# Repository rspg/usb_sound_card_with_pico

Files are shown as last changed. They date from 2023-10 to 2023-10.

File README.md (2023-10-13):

:point_right: [Japanese](./README_jp.md)

# USB Sound Card with Raspberry Pi Pico

## Introduction

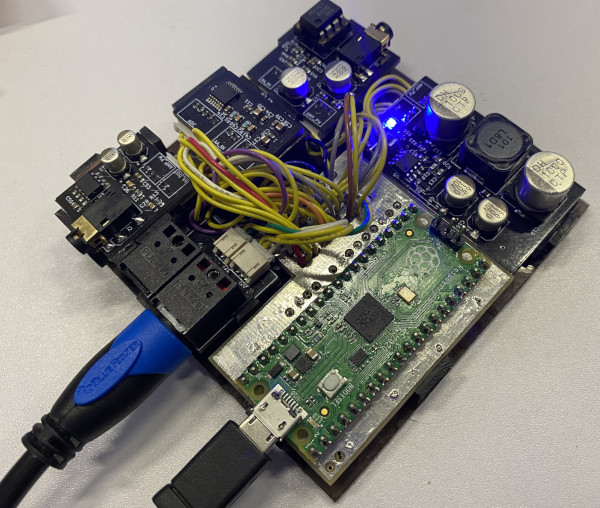
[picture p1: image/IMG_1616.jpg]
Complete image


This is a project for a USB sound card constructed with a Raspberry Pi Pico microcontroller board.  
Hardware schematics and firmware sourcecode are included.

## Features

- USB Audio Class 2.0 (Connected by USB 2.0 Full speed)
- 2ch Line in
- 2ch Line out
- 2ch SPDIF in
- 2ch SPDIF out
- 2ch Headphone out
- Maximum resolution is 24bit
- Maximum frequency is 96KHz

In/out USB data streams cannot activate simultaneously at 24-bit/96KHz due to a lack of transfer bandwidth.
"Line in" and "SPDIF in" are mixed into one buffer to save USB bandwidth. Each volume can be controlled via a generic USB driver. (Currently, it only supports Windows WinUSB.)

## Hardware

I used KiCad6 to design the schematics.  
If you want to view the schematics, Please download [KiCad 6 or later](https://www.kicad.org/).

The hardware design is simple and lacks ingenuity because I am not an electronics expert.
But I designed the schematics with the concept of separating modules by function to facilitate testing and adding other functions.  
Electronic components which are used are general and easily obtainable.   
The DAC uses PCM5102a and may be easily replaced with any of the PCM510x series. You can choose depending on their availability (although I have never tried this).

## Firmware 

The firmware is wrote by C and C++. 
SPDIF control does not use dedicated hardware and is implemented by the software using one of Pico's features called PIO. It allows running I/O independently of the main processor.
Similar to the schematics, the software is also organized by function. Each hardware function is represented as a class in the software.

To build the firmware, you should first install Pico's SDK and CMake.
For detailed instructions, please refer to the following resources.
- [Raspberry Pi Documentation The C/C++ SDK](https://www.raspberrypi.com/documentation/microcontrollers/c_sdk.html)  
- [CMake](https://cmake.org/)

Let's prepare a directory for Cmake setup.
> mkdir build  
> cd build  

For standard setup
> cmake ..  

With tracing log
> cmake .. -DLOG=1   

'LOG' is passed to tinyusb's debug level. That description is [here](https://docs.tinyusb.org/en/latest/reference/getting_started.html#log).

With profiling
> cmake .. -DPROFILE=1

To usb device control use TinyUSB. It is included in PicoSDK.
TinyUSB for Pico has a problem what memory deallocation of endpoint. Therefore, I prepared [a patch](patch/tinyusb-rp2040-allow-memory-preallocation.patch) for avoiding it. 
If you encounter to crashing the device in TinyUSB memory allocation,
It may resolve by applying [the patch](patch/tinyusb-rp2040-allow-memory-preallocation.patch) to TinyUSB.

## Debugging

The device outputs tracing log to serial port (CDC) owned myself. You can see the contents via serial monitor.   
And following commands are usable via serial monitor input.

> stats_on

Turn on the output of internal statistics every 0.5 seconds when the LOG is greater than 0.
 
> stats_off

Turn on output of internal stats.

> perf

Output measured performance statistics when profiling is enabled.

## Device unique request (Windows Only)
Unique requests to control internal behaviors from the host device have been implemented in the firmware.
If the host OS is Windows, the device requests the installation of the WinUSB driver to the OS through the Microsoft OS Descriptor description. This enables user-mode applications on the host to send requests to the device.

[control_uwp](control_uwp) is an application to controls the device volumes by using WinUSB via Windows Runtime.
To building requires [Visual Studio 2022 with C# UWP application development](https://visualstudio.microsoft.com/).

## References
- [Raspberry Pi Pico Datasheet](https://datasheets.raspberrypi.com/pico/pico-datasheet.pdf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.)  
- [RP2040 Datasheet](https://datasheets.raspberrypi.com/rp2040/rp2040-datasheet.pdf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.)    
- [SPECIFICATION OF THE DIGITAL AUDIO INTERFACE (The AES/EBU interface)](https://tech.ebu.ch/docs/tech/tech3250.pdf)
- [Texas Instruments PCM510xA 2.1 VRMS, 112/106/100 dB Audio Stereo DAC with PLL and 32-bit, 384 kHz PCM Interface](https://www.ti.com/lit/ds/symlink/pcm5102a.pdf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)
- [Texas Instruments PCM1808 Single-Ended, Analog-Input 24-Bit, 96-kHz Stereo ADC](https://www.ti.com/jp/lit/ds/symlink/pcm1808.pdf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)

## Disclaimer

I am not responsible and cannot guarantee any damage or injury that may occur if you decide to undertake this project.
Please keep in mind that this is a DIY project.

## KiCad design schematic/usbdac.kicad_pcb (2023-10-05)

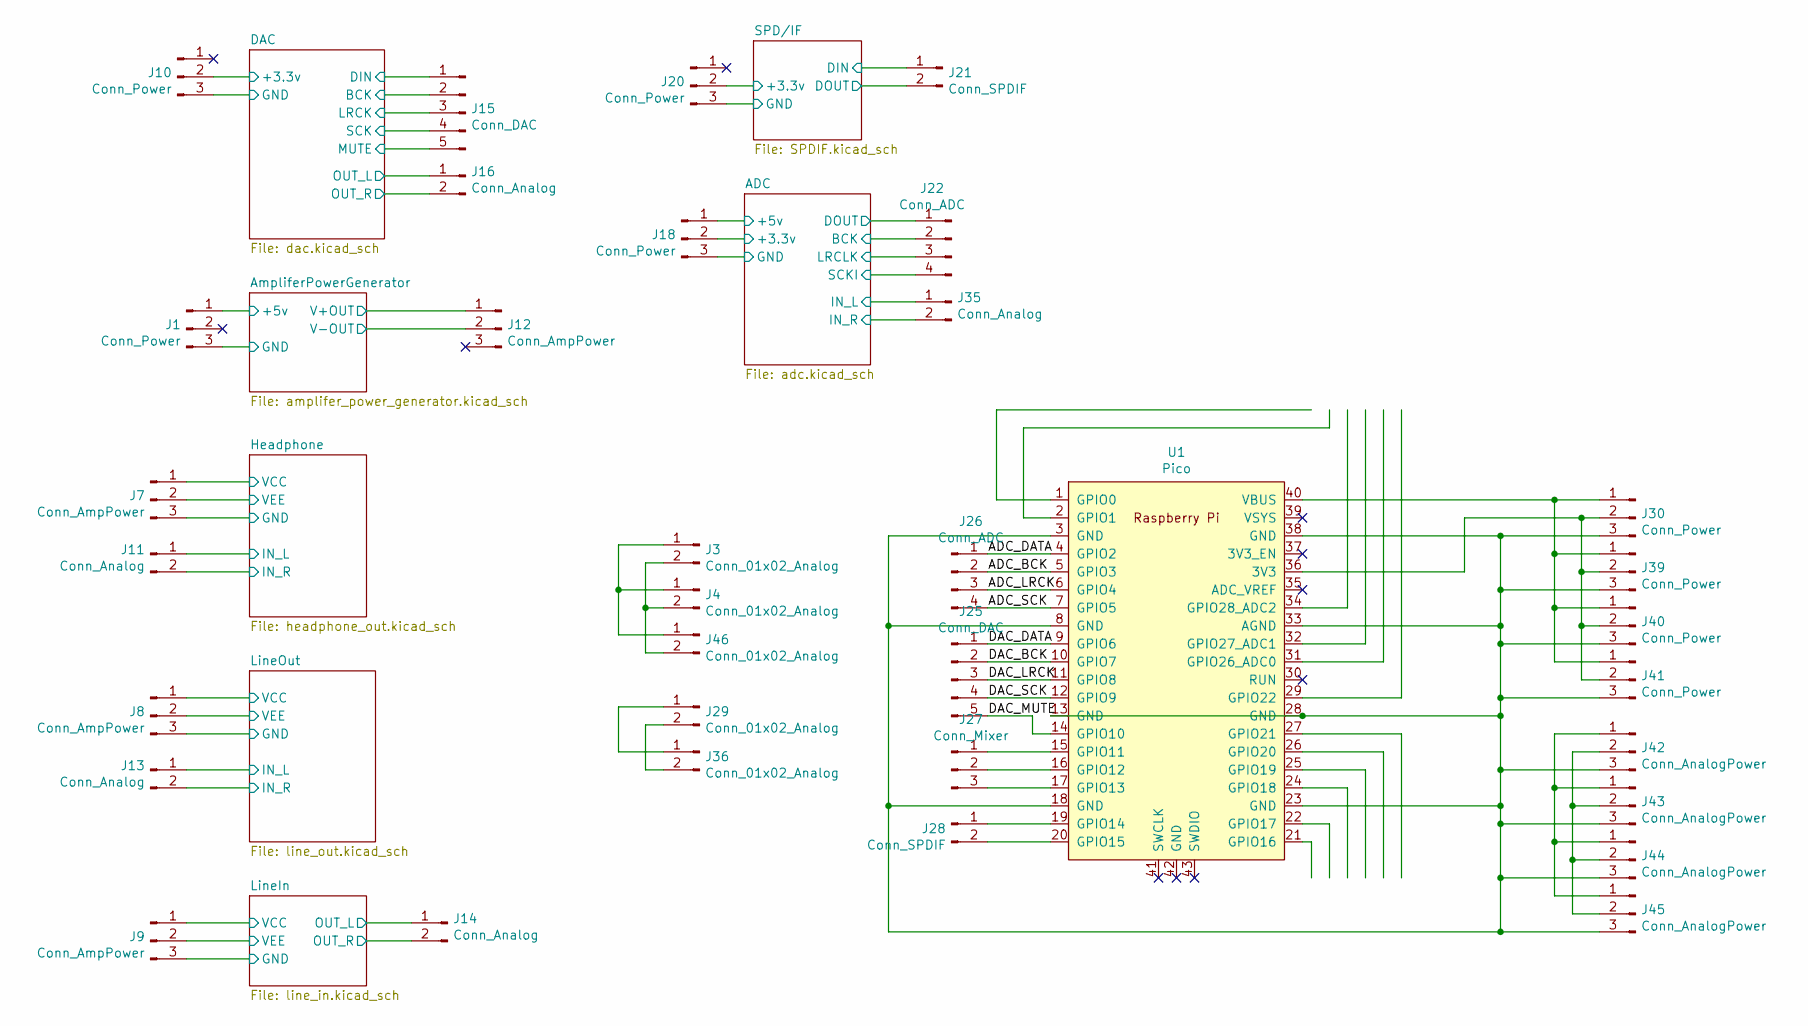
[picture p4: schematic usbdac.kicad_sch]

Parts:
J1, J10, J18, J20: Conn_Power; JST_ZH_S2B_ZR_1x03_P1.50mm_Horizontal_2layer
J3, J4, J29, J36, J46: Conn_01x02_Analog; PinHeader_1x02_P2.00mm_Vertical
J7, J8, J9, J12: Conn_AmpPower; JST_ZH_S2B_ZR_1x03_P1.50mm_Horizontal_2layer
J11, J13, J14, J16, J35: Conn_Analog; JST_ZH_S2B_ZR_1x02_P1.50mm_Horizontal_2layer
J15: Conn_DAC; JST_ZH_S2B_ZR_1x05_P1.50mm_Horizontal_2layer
J21: Conn_SPDIF; JST_ZH_S2B_ZR_1x02_P1.50mm_Horizontal_2layer
J22: Conn_ADC; JST_ZH_S2B_ZR_1x05_P1.50mm_Horizontal_2layer
J25: Conn_DAC; PinHeader_1x05_P2.00mm_Vertical
J26: Conn_ADC; PinHeader_1x04_P2.00mm_Vertical
J27: Conn_Mixer; PinHeader_1x03_P2.00mm_Vertical
J28: Conn_SPDIF; PinHeader_1x02_P2.00mm_Vertical
J30, J39, J40, J41: Conn_Power; PinHeader_1x03_P2.00mm_Vertical
J42, J43, J44, J45: Conn_AnalogPower; PinHeader_1x03_P2.00mm_Vertical
U1: Pico; RPi_Pico_WithPinHeader

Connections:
/ADC/+3.3v: J18.2; also elsewhere on the board
/ADC/+5v: J18.1; also elsewhere on the board
/ADC/BCK: J22.2; also elsewhere on the board
/ADC/DOUT: J22.1; also elsewhere on the board
/ADC/GND: J18.3; also elsewhere on the board
/ADC/IN_L: J35.1; also elsewhere on the board
/ADC/IN_R: J35.2; also elsewhere on the board
/ADC/LRCLK: J22.3; also elsewhere on the board
/ADC/SCKI: J22.4; also elsewhere on the board
/ADC_BCK: J26.2, U1.5 (GPIO3)
/ADC_DATA: J26.1, U1.4 (GPIO2)
/ADC_LRCK: J26.3, U1.6 (GPIO4)
/ADC_SCK: J26.4, U1.7 (GPIO5)
/AmpliferPowerGenerator/+5v: J1.1, J12.1; also elsewhere on the board
/AmpliferPowerGenerator/GND: J1.3; also elsewhere on the board
/AmpliferPowerGenerator/V-OUT: J12.2; also elsewhere on the board
/DAC/+3.3v: J10.2; also elsewhere on the board
/DAC/BCK: J15.2; also elsewhere on the board
/DAC/DIN: J15.1; also elsewhere on the board
/DAC/GND: J10.3; also elsewhere on the board
/DAC/LRCK: J15.3; also elsewhere on the board
/DAC/MUTE: J15.5; also elsewhere on the board
/DAC/OUT_L: J16.1; also elsewhere on the board
/DAC/OUT_R: J16.2; also elsewhere on the board
/DAC/SCK: J15.4; also elsewhere on the board
/DAC_BCK: J25.2, U1.10 (GPIO7)
/DAC_DATA: J25.1, U1.9 (GPIO6)
/DAC_LRCK: J25.3, U1.11 (GPIO8)
/DAC_MUTE: J25.5, U1.14 (GPIO10)
/DAC_SCK: J25.4, U1.12 (GPIO9)
/Headphone/GND: J7.3; also elsewhere on the board
/Headphone/IN_L: J11.1; also elsewhere on the board
/Headphone/IN_R: J11.2; also elsewhere on the board
/Headphone/VCC: J7.1; also elsewhere on the board
/Headphone/VEE: J7.2; also elsewhere on the board
/LineIn/GND: J9.3; also elsewhere on the board
/LineIn/OUT_L: J14.1; also elsewhere on the board
/LineIn/OUT_R: J14.2; also elsewhere on the board
/LineIn/VCC: J9.1; also elsewhere on the board
/LineIn/VEE: J9.2; also elsewhere on the board
/LineOut/GND: J8.3; also elsewhere on the board
/LineOut/IN_L: J13.1; also elsewhere on the board
/LineOut/IN_R: J13.2; also elsewhere on the board
/LineOut/VCC: J8.1; also elsewhere on the board
/LineOut/VEE: J8.2; also elsewhere on the board
/SPD/IF/+3.3v: J20.2; also elsewhere on the board
/SPD/IF/DIN: J21.1; also elsewhere on the board
/SPD/IF/DOUT: J21.2; also elsewhere on the board
/SPD/IF/GND: J20.3; also elsewhere on the board
unnamed: J3.1, J4.1, J46.1
unnamed: J3.2, J4.2, J46.2
unnamed: J27.1, U1.15 (GPIO11)
unnamed: J27.2, U1.16 (GPIO12)
unnamed: J27.3, U1.17 (GPIO13)
unnamed: J28.1, U1.19 (GPIO14)
unnamed: J28.2, U1.20 (GPIO15)
unnamed: J29.1, J36.1
unnamed: J29.2, J36.2
unnamed: J30.1, J39.1, J40.1, J41.1, U1.40 (VBUS)
unnamed: J30.2, J39.2, J40.2, J41.2, U1.36 (3V3)
unnamed: J30.3, J39.3, J40.3, J41.3, J42.3, J43.3, J44.3, J45.3, U1.3 (GND), U1.8 (GND), U1.13 (GND), U1.18 (GND), U1.23 (GND), U1.28 (GND), U1.33 (AGND), U1.38 (GND)
unnamed: J42.1, J43.1, J44.1, J45.1
unnamed: J42.2, J43.2, J44.2, J45.2

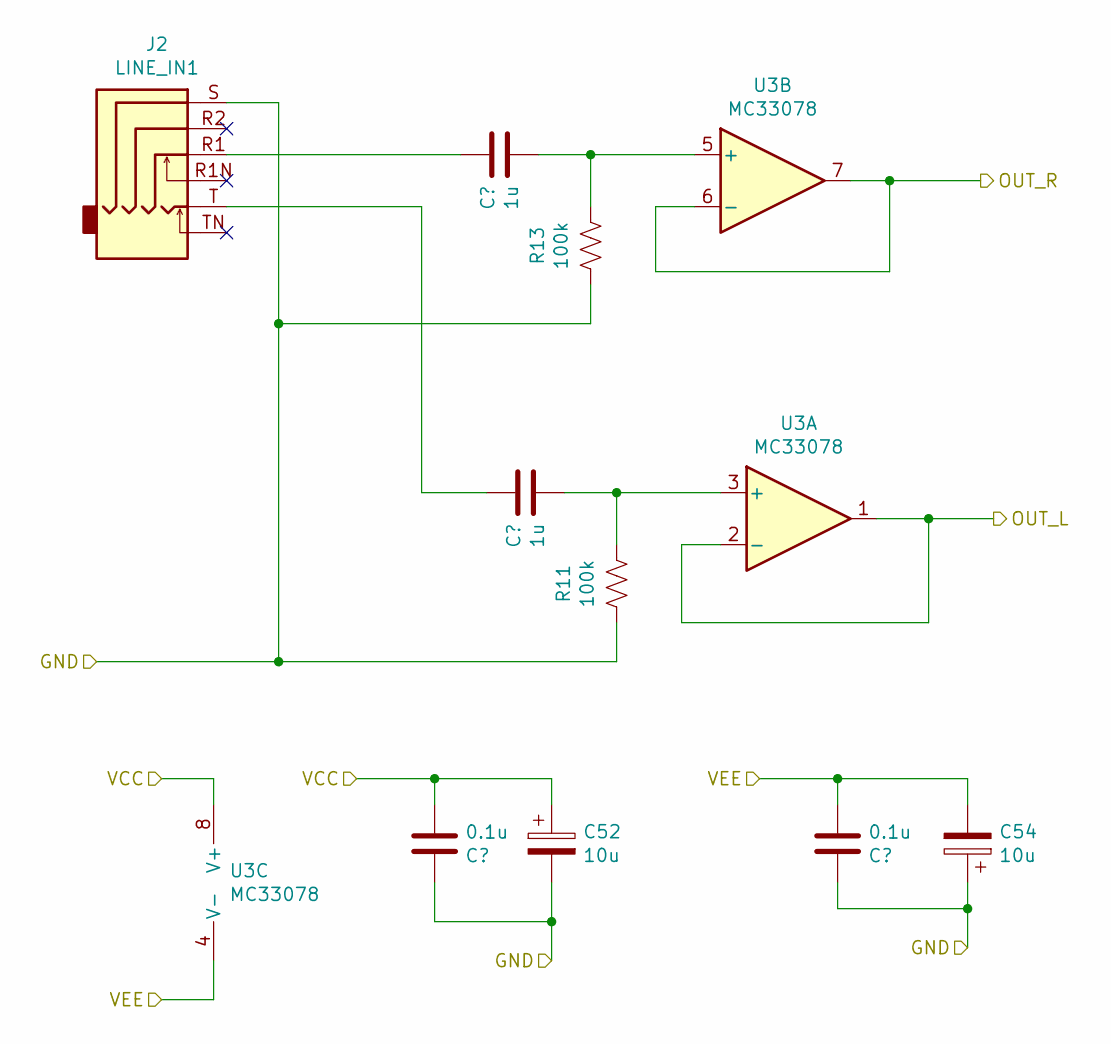
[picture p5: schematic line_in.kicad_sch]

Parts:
C26, C28: 1u; C_0603_1608Metric
C51, C53: 0.1u; C_0603_1608Metric
C52, C54: 10u; CP_Elec_4x3.9
J2: LINE_IN1; Jack_3.5mm_PJ31060-I_Horizontal
R11, R13: 100k; R_0603_1608Metric
U3: MC33078; SO-8_3.9x4.9mm_P1.27mm

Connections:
/LineIn/GND: C51.2, C52.2, C53.2, C54.1, J2.S, R11.1, R13.1; also elsewhere on the board
/LineIn/OUT_L: U3.1, U3.2 (-); also elsewhere on the board
/LineIn/OUT_R: U3.6 (-), U3.7; also elsewhere on the board
/LineIn/VCC: C51.1, C52.1, U3.8 (V+); also elsewhere on the board
/LineIn/VEE: C53.1, C54.2, U3.4 (V-); also elsewhere on the board
unnamed: C26.2, J2.T
unnamed: C28.2, J2.R1
unnamed: C26.1, R11.2, U3.3 (+)
unnamed: C28.1, R13.2, U3.5 (+)

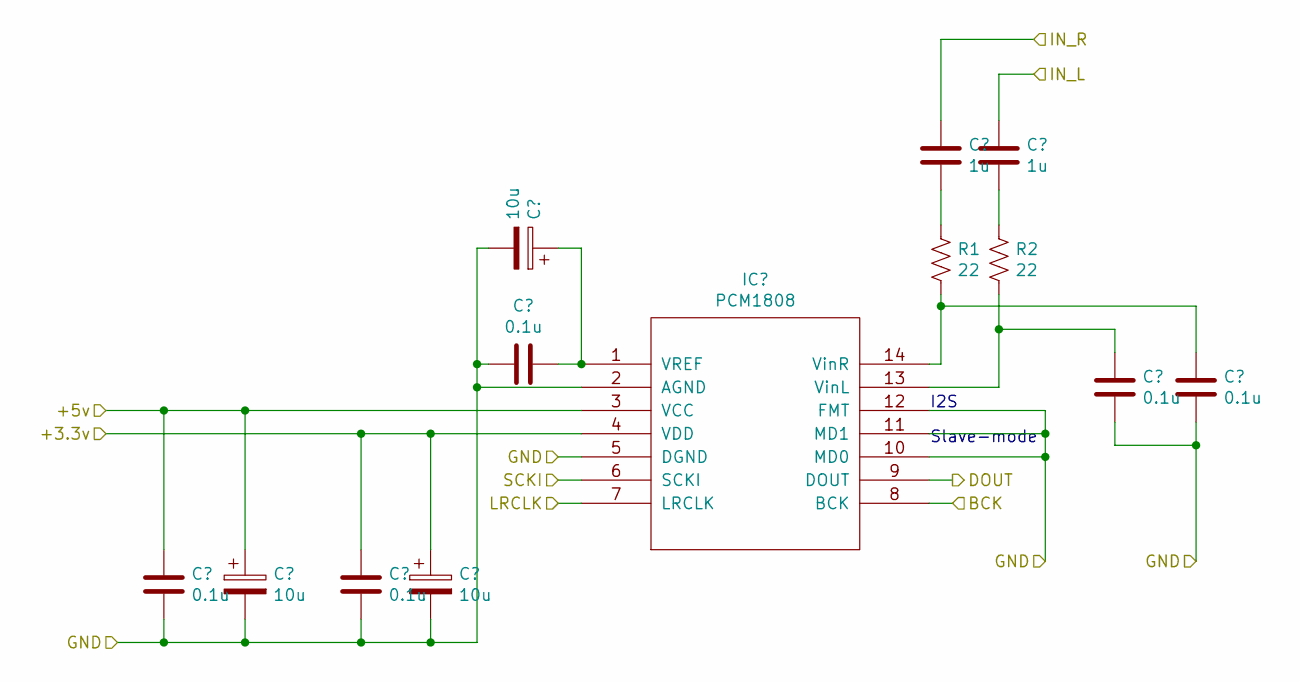
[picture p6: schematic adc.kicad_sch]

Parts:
C11, C14, C34, C36, C39: 0.1u; C_0603_1608Metric
C35, C37, C38: 10u; C_0603_1608Metric
C40, C41: 1u; C_0603_1608Metric
IC1: PCM1808; TI_R-PDSO-G14
R1, R2: 22; R_0603_1608Metric

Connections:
/ADC/+3.3v: C36.2, C37.1, IC1.4 (VDD); also elsewhere on the board
/ADC/+5v: C34.2, C35.1, IC1.3 (VCC); also elsewhere on the board
/ADC/BCK: IC1.8 (BCK); also elsewhere on the board
/ADC/DOUT: IC1.9 (DOUT); also elsewhere on the board
/ADC/GND: C11.1, C14.1, C34.1, C35.2, C36.1, C37.2, C38.2, C39.1, IC1.2 (AGND), IC1.5 (DGND), IC1.10 (MD0), IC1.11 (MD1), IC1.12 (FMT); also elsewhere on the board
/ADC/IN_L: C41.2; also elsewhere on the board
/ADC/IN_R: C40.2; also elsewhere on the board
/ADC/LRCLK: IC1.7 (LRCLK); also elsewhere on the board
/ADC/SCKI: IC1.6 (SCKI); also elsewhere on the board
unnamed: C40.1, R1.1
unnamed: C41.1, R2.1
unnamed: C38.1, C39.2, IC1.1 (VREF)
unnamed: C11.2, IC1.13 (VinL), R2.2
unnamed: C14.2, IC1.14 (VinR), R1.2

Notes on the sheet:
Slave-mode
I2S

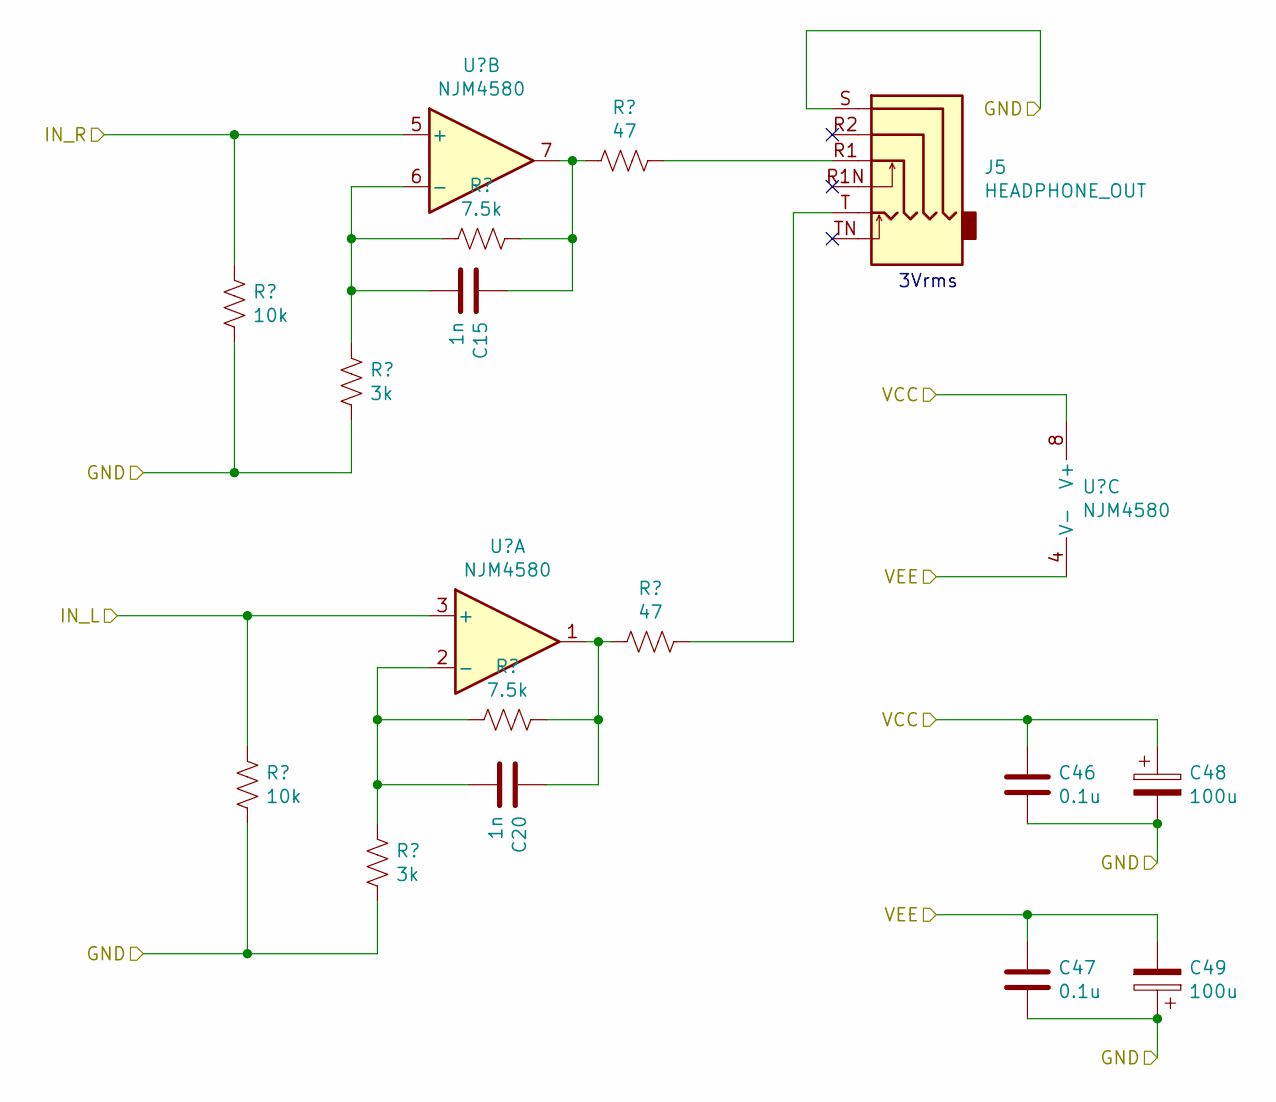
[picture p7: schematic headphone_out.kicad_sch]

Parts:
C15, C20: 1n; C_0603_1608Metric
C46, C47: 0.1u; C_0603_1608Metric
C48, C49: 100u; CP_Elec_6.3x5.4
J5: HEADPHONE_OUT; Jack_3.5mm_PJ31060-I_Horizontal
R3, R4: 10k; R_0603_1608Metric
R45, R46: 3k; R_0603_1608Metric
R47, R48: 7.5k; R_0603_1608Metric
R49, R50: 47; R_0603_1608Metric
U16: NJM4580; DIP-8_W7.62mm_SMDSocket_SmallPads

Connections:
/Headphone/GND: C46.2, C47.2, C48.2, C49.1, J5.S, R3.2, R4.2, R45.2, R46.2; also elsewhere on the board
/Headphone/IN_L: R4.1, U16.3 (+); also elsewhere on the board
/Headphone/IN_R: R3.1, U16.5 (+); also elsewhere on the board
/Headphone/VCC: C46.1, C48.1, U16.8 (V+); also elsewhere on the board
/Headphone/VEE: C47.1, C49.2, U16.4 (V-); also elsewhere on the board
unnamed: C15.1, R48.2, R50.1, U16.7
unnamed: C20.1, R47.2, R49.1, U16.1
unnamed: J5.R1, R50.2
unnamed: J5.T, R49.2
unnamed: C20.2, R45.1, R47.1, U16.2 (-)
unnamed: C15.2, R46.1, R48.1, U16.6 (-)

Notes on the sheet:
3Vrms

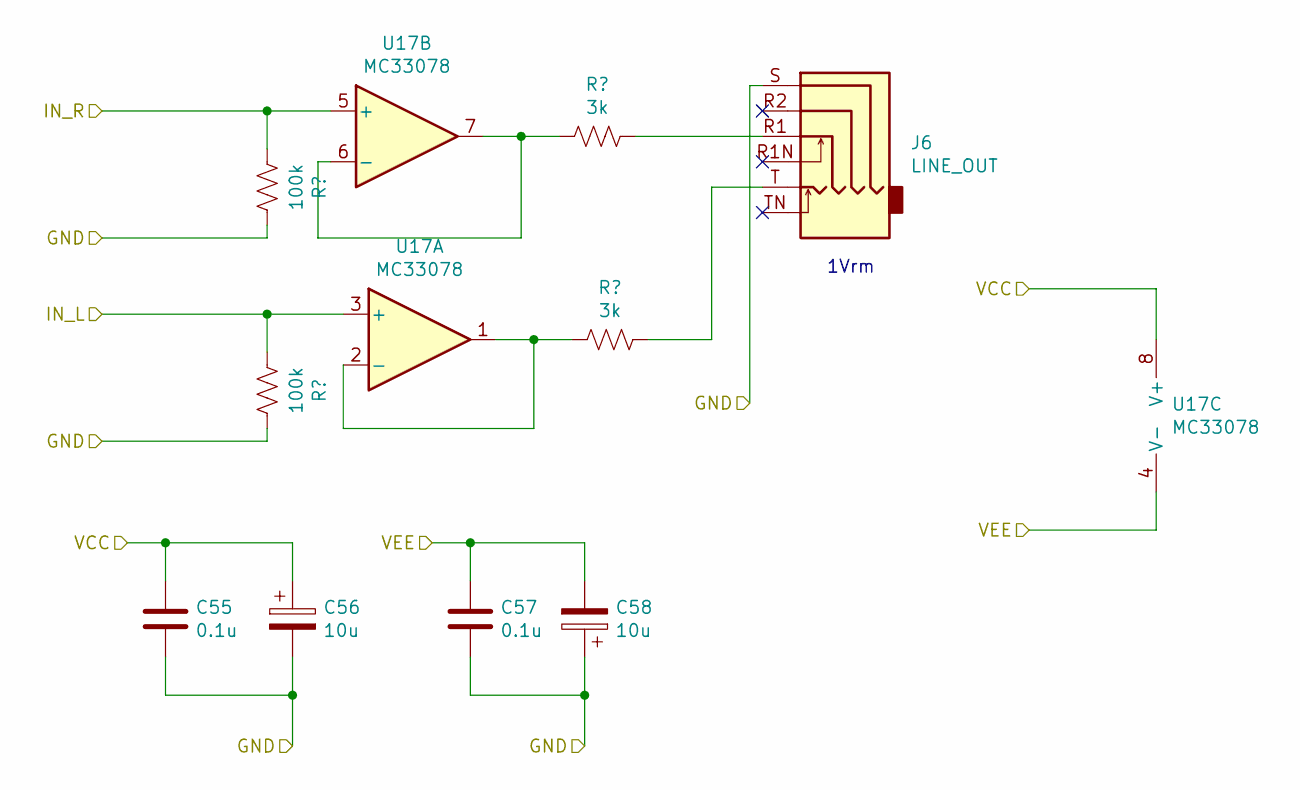
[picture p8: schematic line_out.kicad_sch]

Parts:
C55, C57: 0.1u; C_0603_1608Metric
C56, C58: 10u; CP_Elec_4x3.9
J6: LINE_OUT; Jack_3.5mm_PJ31060-I_Horizontal
R5, R44: 100k; R_0603_1608Metric
R51, R52: 3k; R_0603_1608Metric
U17: MC33078; SO-8_3.9x4.9mm_P1.27mm

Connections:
/LineOut/GND: C55.2, C56.2, C57.2, C58.1, J6.S, R5.2, R44.2; also elsewhere on the board
/LineOut/IN_L: R44.1, U17.3 (+); also elsewhere on the board
/LineOut/IN_R: R5.1, U17.5 (+); also elsewhere on the board
/LineOut/VCC: C55.1, C56.1, U17.8 (V+); also elsewhere on the board
/LineOut/VEE: C57.1, C58.2, U17.4 (V-); also elsewhere on the board
unnamed: J6.R1, R52.2
unnamed: J6.T, R51.2
unnamed: R51.1, U17.1, U17.2 (-)
unnamed: R52.1, U17.6 (-), U17.7

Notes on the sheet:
1Vrm

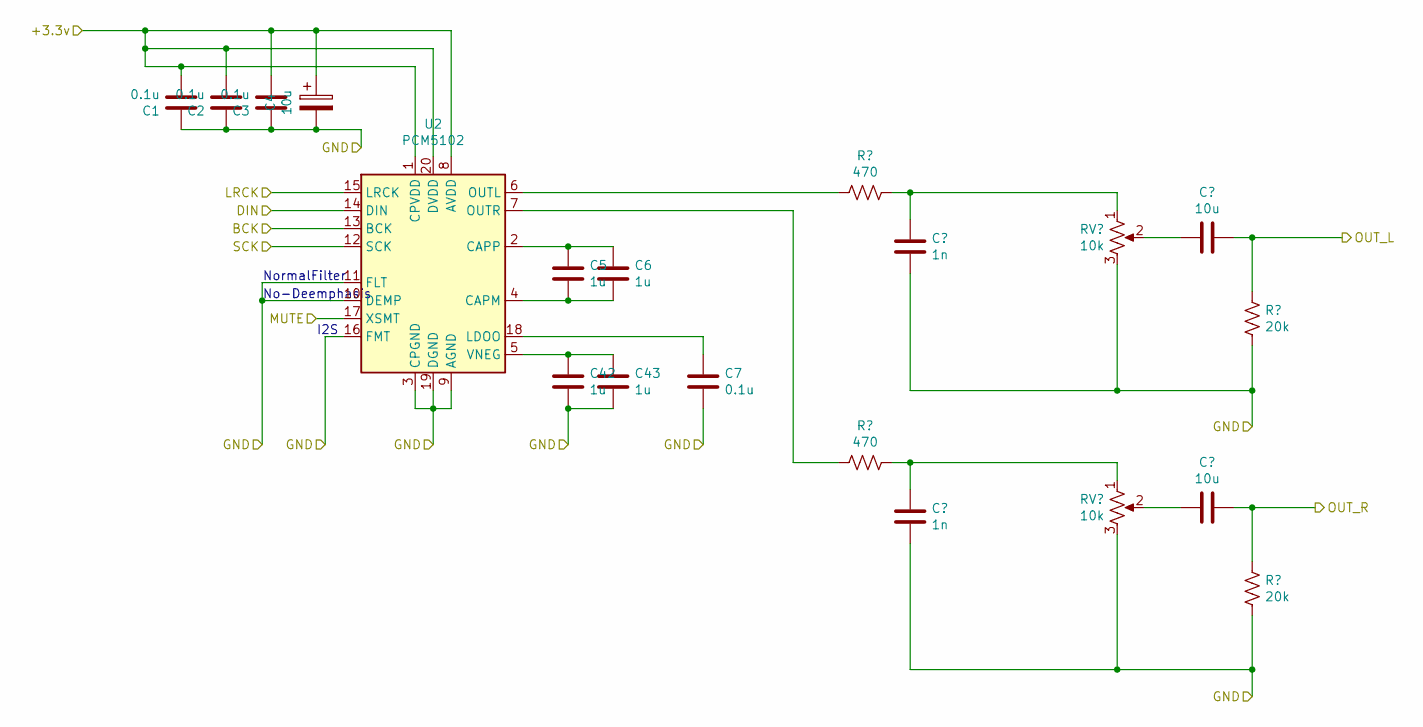
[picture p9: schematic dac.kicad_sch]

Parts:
C1, C2, C3, C7: 0.1u; C_0603_1608Metric
C4, C10, C23: 10u; C_0603_1608Metric
C5, C6, C42, C43: 1u; C_0603_1608Metric
C8, C9: 1n; C_0603_1608Metric
R6, R7: 470; R_0603_1608Metric
R8, R9: 20k; R_0603_1608Metric
RV1, RV2: 10k; Potentiometer_Bourns_TC33X_Vertical
U2: PCM5102; TSSOP-20_4.4x6.5mm_P0.65mm

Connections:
/DAC/+3.3v: C1.2, C2.2, C3.2, C4.1, U2.1 (CPVDD), U2.8 (AVDD), U2.20 (DVDD); also elsewhere on the board
/DAC/BCK: U2.13 (BCK); also elsewhere on the board
/DAC/DIN: U2.14 (DIN); also elsewhere on the board
/DAC/GND: C1.1, C2.1, C3.1, C4.2, C7.2, C8.2, C9.2, C42.2, C43.2, R8.2, R9.2, RV1.3, RV2.3, U2.3 (CPGND), U2.9 (AGND), U2.10 (DEMP), U2.11 (FLT), U2.16 (FMT), U2.19 (DGND); also elsewhere on the board
/DAC/LRCK: U2.15 (LRCK); also elsewhere on the board
/DAC/MUTE: U2.17 (XSMT); also elsewhere on the board
/DAC/OUT_L: C10.2, R8.1; also elsewhere on the board
/DAC/OUT_R: C23.2, R9.1; also elsewhere on the board
/DAC/SCK: U2.12 (SCK); also elsewhere on the board
unnamed: C8.1, R6.2, RV1.1
unnamed: C9.1, R7.2, RV2.1
unnamed: C10.1, RV1.2
unnamed: C23.1, RV2.2
unnamed: C5.2, C6.2, U2.4 (CAPM)
unnamed: C5.1, C6.1, U2.2 (CAPP)
unnamed: C7.1, U2.18 (LDOO)
unnamed: R6.1, U2.6 (OUTL)
unnamed: R7.1, U2.7 (OUTR)
unnamed: C42.1, C43.1, U2.5 (VNEG)

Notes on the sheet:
I2S
No-Deemphasis
NormalFilter

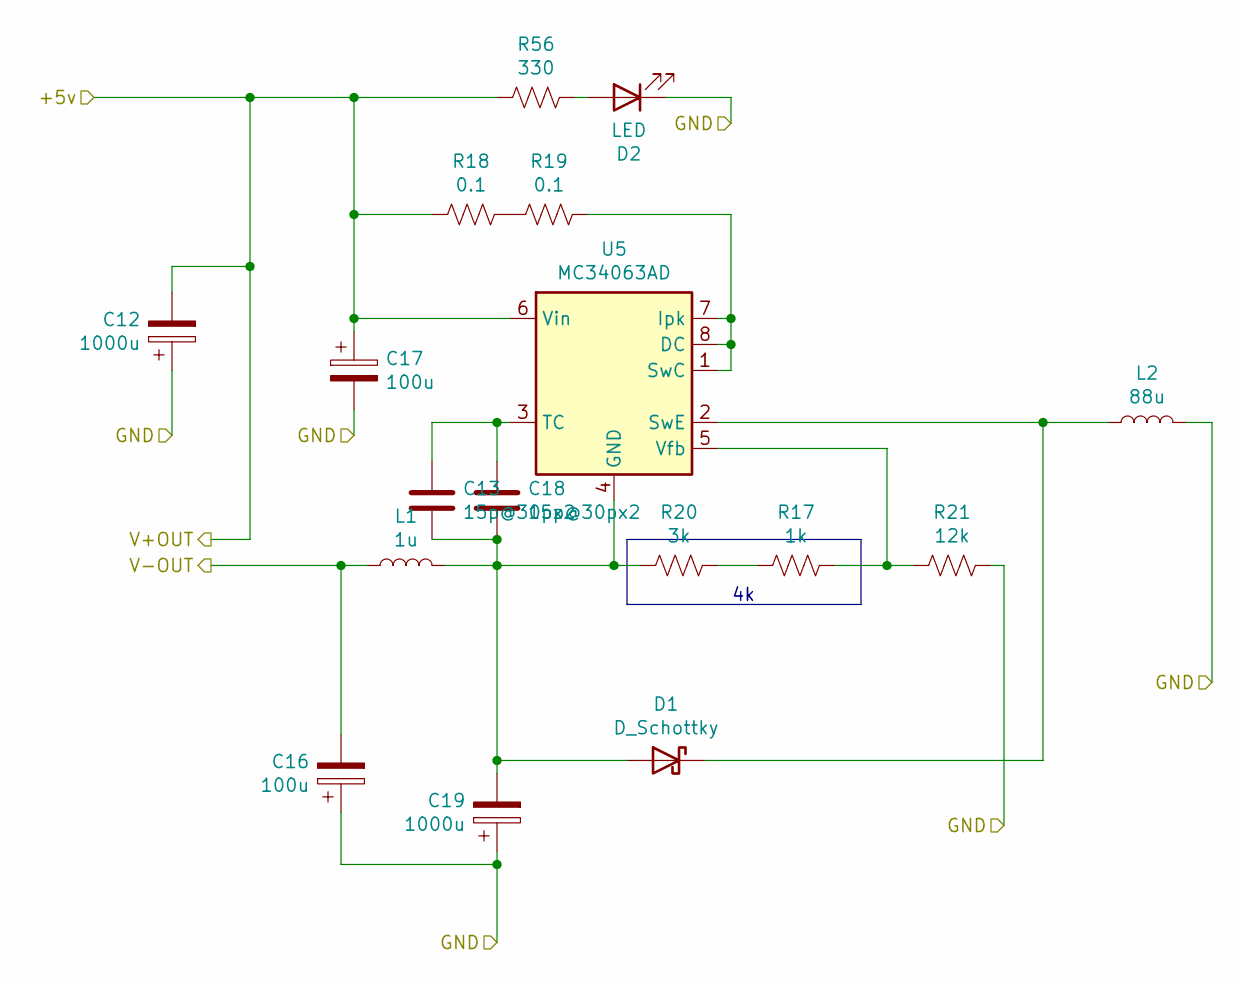
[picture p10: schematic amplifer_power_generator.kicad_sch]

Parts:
C12, C19: 1000u; CP_Elec_10x10
C13, C18: 15p@30px2; C_0603_1608Metric
C16, C17: 100u; CP_Elec_6.3x5.4
D1: D_Schottky; CUS01
D2: LED; LED_0805_2012Metric
L1: 1u; L_0603_1608Metric
L2: 88u; L_Taiyo-Yuden_NR-10050_9.8x10.0mm
R17: 1k; R_0603_1608Metric
R18, R19: 0.1; R_1210_3225Metric
R20: 3k; R_0603_1608Metric
R21: 12k; R_0603_1608Metric
R56: 330; R_0603_1608Metric
U5: MC34063AD; SOIC-8_3.9x4.9mm_P1.27mm

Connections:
/AmpliferPowerGenerator/+5v: C12.2, C17.1, R18.1, R56.1, U5.6 (Vin); also elsewhere on the board
/AmpliferPowerGenerator/GND: C12.1, C16.1, C17.2, C19.1, D2.1 (K), L2.2, R21.2; also elsewhere on the board
/AmpliferPowerGenerator/V-OUT: C16.2, L1.1; also elsewhere on the board
unnamed: C13.2, C18.2, C19.2, D1.2 (A), L1.2, R20.1, U5.4 (GND)
unnamed: D1.1 (K), L2.1, U5.2 (SwE)
unnamed: D2.2 (A), R56.2
unnamed: R17.1, R20.2
unnamed: R18.2, R19.1
unnamed: R19.2, U5.1 (SwC), U5.7 (Ipk), U5.8 (DC)
unnamed: C13.1, C18.1, U5.3 (TC)
unnamed: R17.2, R21.1, U5.5 (Vfb)

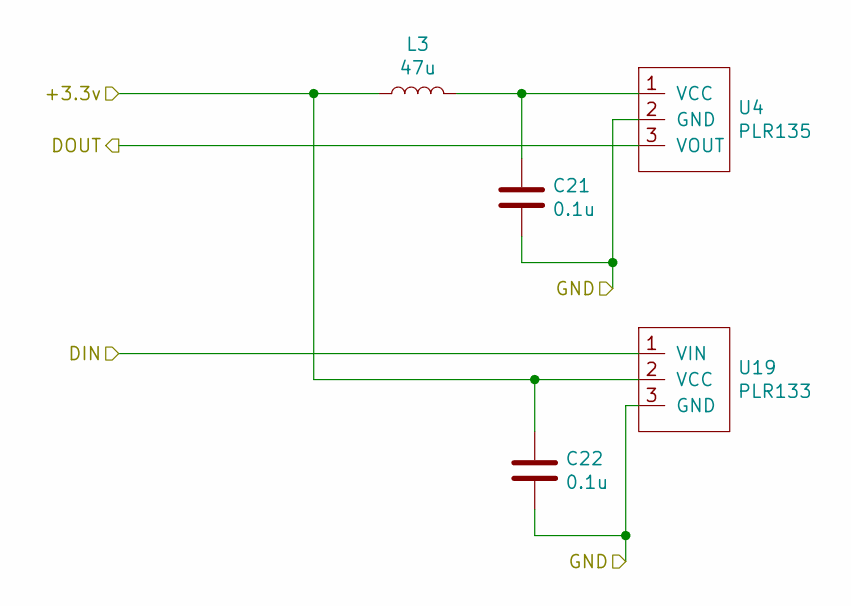
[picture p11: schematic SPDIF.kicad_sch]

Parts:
C21, C22: 0.1u; C_0603_1608Metric
L3: 47u; A915AY-100M
U4: PLR135; PLR133-135
U19: PLR133; PLR133-135

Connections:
/SPD/IF/+3.3v: C22.1, L3.1, U19.2 (VCC); also elsewhere on the board
/SPD/IF/DIN: U19.1 (VIN); also elsewhere on the board
/SPD/IF/DOUT: U4.3 (VOUT); also elsewhere on the board
/SPD/IF/GND: C21.2, C22.2, U4.2 (GND), U19.3 (GND); also elsewhere on the board
unnamed: C21.1, L3.2, U4.1 (VCC)

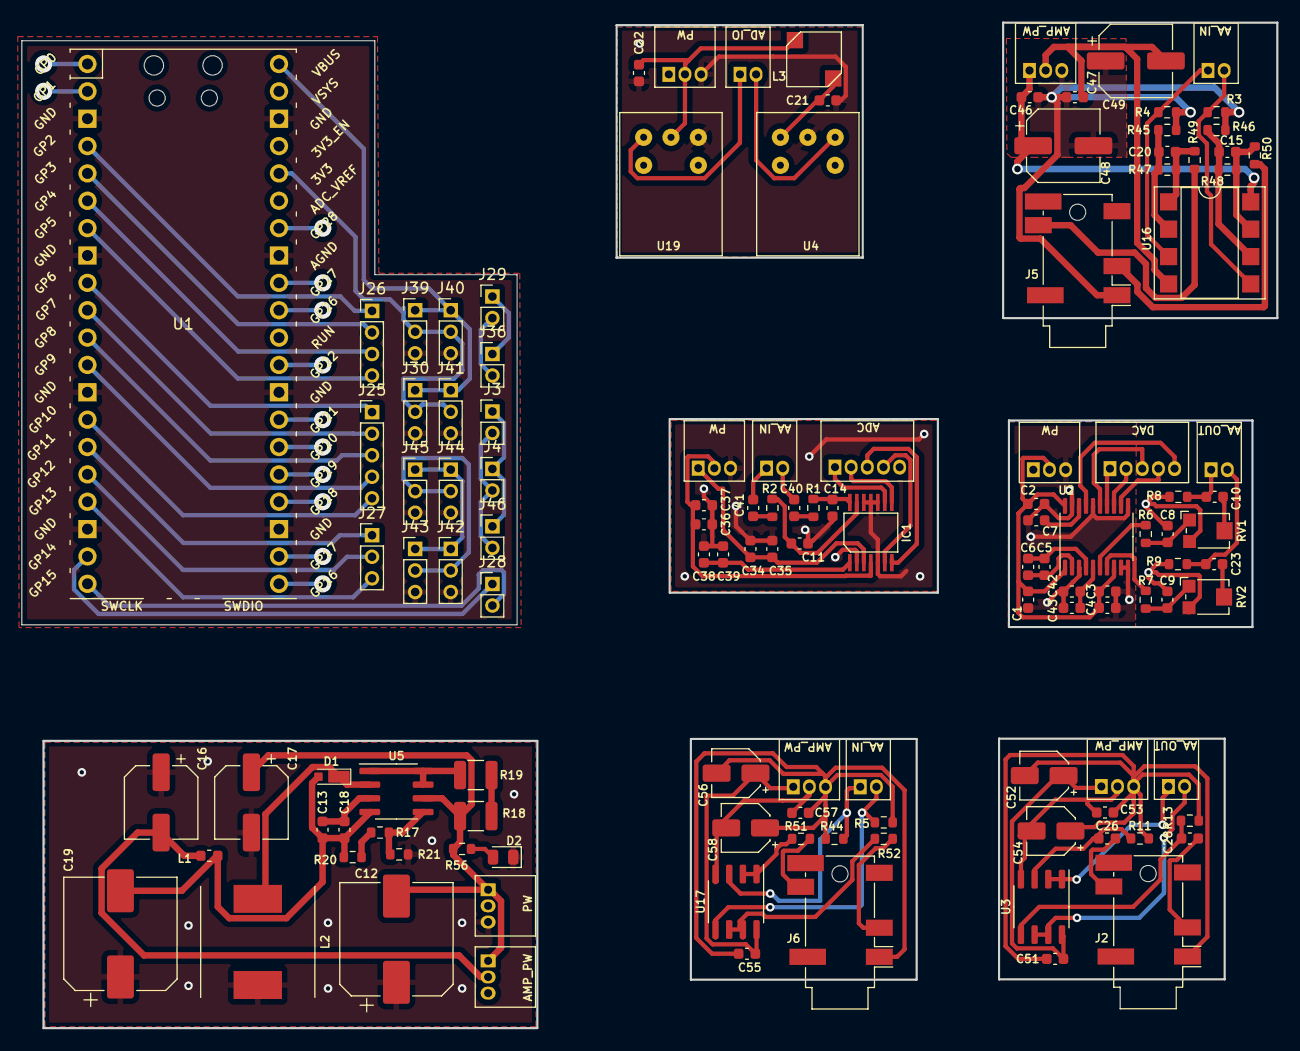
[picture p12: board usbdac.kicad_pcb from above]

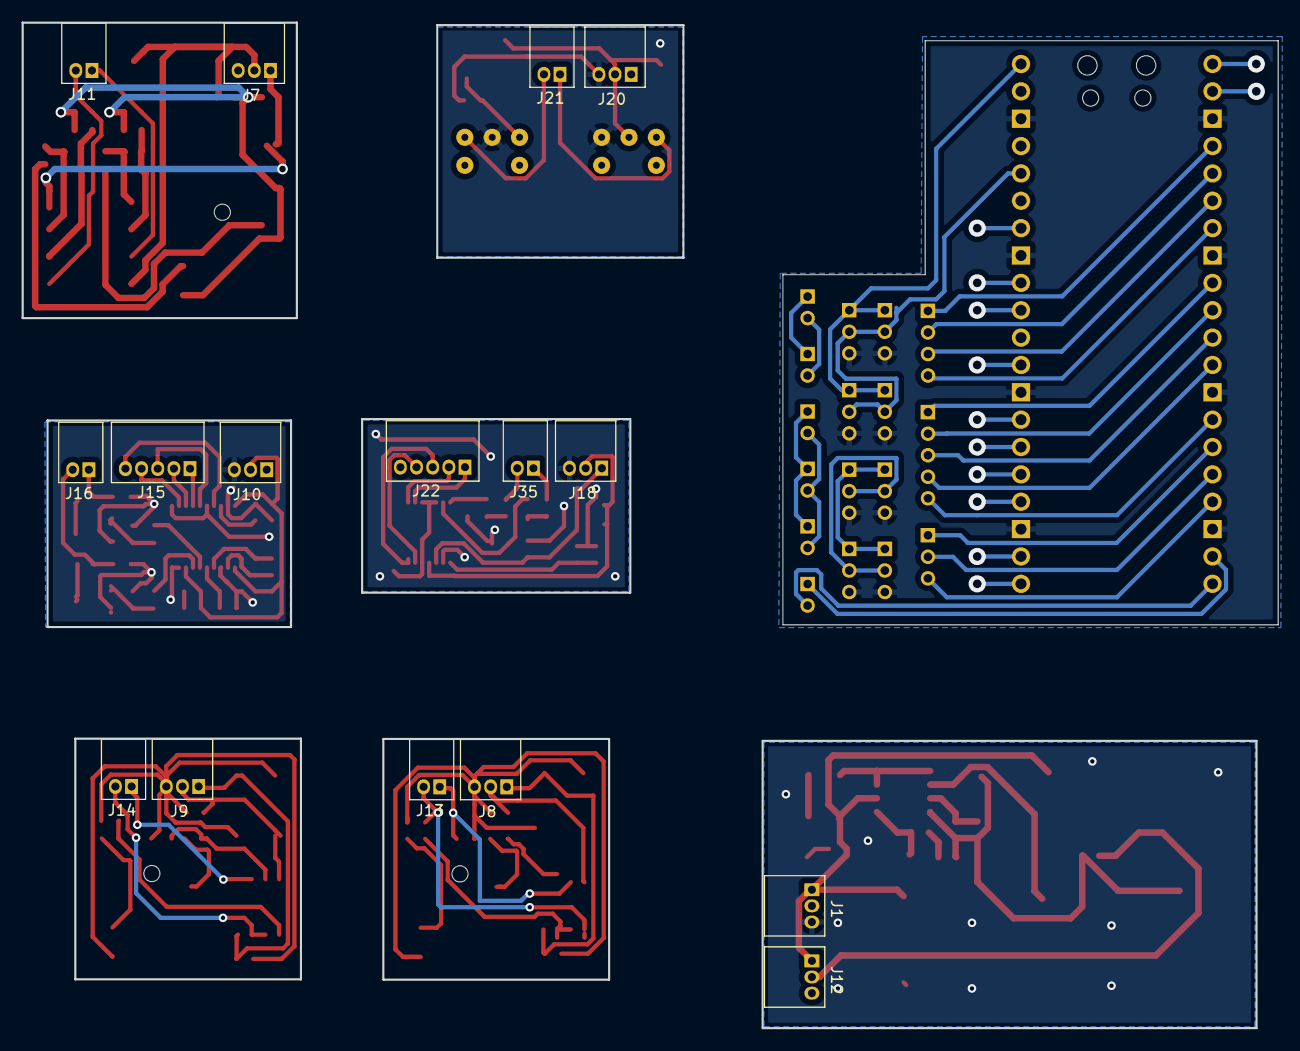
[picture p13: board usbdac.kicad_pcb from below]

Board: 2 copper layers, 116.6 x 93.3 mm, 125 parts (16 on the bottom side), 101 nets.

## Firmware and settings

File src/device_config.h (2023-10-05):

#pragma once

#include <stdint.h>
#include "usb_config.h"

#define SPDIF_OUTPUT_ENABLE     1
#define DAC_OUTPUT_ENABLE       1
#define SPDIF_INPUT_ENABLE      1
#define ADC_INPUT_ENABLE        1
#define MIXING_INPUT_TO_OUTPUT_ENABLE  1

constexpr uint8_t  device_output_channels = 2;
constexpr uint8_t  device_input_channels = 2;
constexpr uint8_t  max_resolution_bits = 24;
constexpr uint32_t max_sampling_frequency = 96000;
constexpr uint32_t max_byte_per_sample = max_resolution_bits*device_output_channels/8; // 24bit 2ch
constexpr size_t   max_output_samples_1ms = max_sampling_frequency*device_output_channels/1000;
constexpr size_t   max_input_samples_1ms = max_sampling_frequency*device_input_channels/1000;


namespace gpio_assign
{
    constexpr uint spdif_tx = 14;
    constexpr uint spdif_rx = 15;

    constexpr uint dac_data = 6;
    constexpr uint dac_bck_lrck = 7;
    constexpr uint dac_sck = 9;
    constexpr uint dac_mute = 10;

    constexpr uint adc_data = 2;
    constexpr uint adc_bck_lrck = 3;
    constexpr uint adc_sck = 5;
}

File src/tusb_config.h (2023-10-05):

/*
 * The MIT License (MIT)
 *
 * Copyright (c) 2019 Ha Thach (tinyusb.org)
 *
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
 */

#ifndef _TUSB_CONFIG_H_
#define _TUSB_CONFIG_H_

#include "usb_config.h"

#ifdef __cplusplus
extern "C" {
#endif

//--------------------------------------------------------------------
// COMMON CONFIGURATION
//--------------------------------------------------------------------

// defined by compiler flags for flexibility
#ifndef CFG_TUSB_MCU
#error CFG_TUSB_MCU must be defined
#endif

#if CFG_TUSB_MCU == OPT_MCU_LPC43XX || CFG_TUSB_MCU == OPT_MCU_LPC18XX || CFG_TUSB_MCU == OPT_MCU_MIMXRT10XX
#define CFG_TUSB_RHPORT0_MODE       (OPT_MODE_DEVICE | OPT_MODE_HIGH_SPEED)
#else
#define CFG_TUSB_RHPORT0_MODE       OPT_MODE_DEVICE
#endif

#ifndef CFG_TUSB_OS
#define CFG_TUSB_OS                 OPT_OS_NONE
#endif

#ifndef CFG_TUSB_DEBUG
#define CFG_TUSB_DEBUG              0
#endif

// Enable Device stack
#define CFG_TUD_ENABLED             1

#define CFG_TUSB_DEBUG_PRINTF       dbg_printf

// CFG_TUSB_DEBUG is defined by compiler in DEBUG build
// #define CFG_TUSB_DEBUG           0

/* USB DMA on some MCUs can only access a specific SRAM region with restriction on alignment.
 * Tinyusb use follows macros to declare transferring memory so that they can be put
 * into those specific section.
 * e.g
 * - CFG_TUSB_MEM SECTION : __attribute__ (( section(".usb_ram") ))
 * - CFG_TUSB_MEM_ALIGN   : __attribute__ ((aligned(4)))
 */
#ifndef CFG_TUSB_MEM_SECTION
#define CFG_TUSB_MEM_SECTION
#endif

#ifndef CFG_TUSB_MEM_ALIGN
#define CFG_TUSB_MEM_ALIGN          __attribute__ ((aligned(4)))
#endif

//--------------------------------------------------------------------
// DEVICE CONFIGURATION
//--------------------------------------------------------------------

#ifndef CFG_TUD_ENDPOINT0_SIZE
#define CFG_TUD_ENDPOINT0_SIZE    64
#endif

//------------- CLASS -------------//
#define CFG_TUD_CDC               (USB_IF_DEBUG_CDC_ENABLE ? 1 : 0)
#define CFG_TUD_MSC               0
#define CFG_TUD_HID               0
#define CFG_TUD_MIDI              0
#define CFG_TUD_AUDIO             (USB_IF_AUDIO_ENABLE ? 1 : 0)
#define CFG_TUD_VENDOR            (USB_IF_CONTROL_ENABLE ? 1 : 0)
#define CFG_TUD_DFU               0

//--------------------------------------------------------------------
// AUDIO CLASS DRIVER CONFIGURATION
//--------------------------------------------------------------------

#if CFG_TUD_AUDIO

extern const unsigned long tud_audio_headset_stereo_desc_len;

#define CFG_TUD_AUDIO_FUNC_1_DESC_LEN             tud_audio_headset_stereo_desc_len

// EP and buffer size - for isochronous EP´s, the buffer and EP size are equal (different sizes would not make sense)
#define CFG_TUD_AUDIO_ENABLE_EP_IN                1

#define CFG_TUD_AUDIO_FUNC_1_EP_SZ_IN             TUD_AUDIO_EP_SIZE(96000, 4, 2)

#define CFG_TUD_AUDIO_FUNC_1_EP_IN_SZ_MAX         CFG_TUD_AUDIO_FUNC_1_EP_SZ_IN // Maximum EP IN size for all AS alternate settings used
#define CFG_TUD_AUDIO_FUNC_1_EP_IN_SW_BUF_SZ      CFG_TUD_AUDIO_FUNC_1_EP_SZ_IN+1

// EP and buffer size - for isochronous EP´s, the buffer and EP size are equal (different sizes would not make sense)
#define CFG_TUD_AUDIO_ENABLE_EP_OUT               1

#define CFG_TUD_AUDIO_FUNC_1_EP_SZ_OUT            TUD_AUDIO_EP_SIZE(96000, 4, 2)

#define CFG_TUD_AUDIO_FUNC_1_EP_OUT_SZ_MAX        CFG_TUD_AUDIO_FUNC_1_EP_SZ_OUT // Maximum EP IN size for all AS alternate settings used
#define CFG_TUD_AUDIO_FUNC_1_EP_OUT_SW_BUF_SZ     CFG_TUD_AUDIO_FUNC_1_EP_SZ_OUT+1

// Number of Standard AS Interface Descriptors (4.9.1) defined per audio function - this is required to be able to remember the current alternate settings of these interfaces - We restrict us here to have a constant number for all audio functions (which means this has to be the maximum number of AS interfaces an audio function has and a second audio function with less AS interfaces just wastes a few bytes)
#define CFG_TUD_AUDIO_FUNC_1_N_AS_INT 	          4

// Size of control request buffer
#define CFG_TUD_AUDIO_FUNC_1_CTRL_BUF_SZ	      64

#define CFG_TUD_AUDIO_ENABLE_FEEDBACK_EP          1
// #define CFG_TUD_AUDIO_ENABLE_FEEDBACK_FORMAT_CORRECTION  1

#endif

#if CFG_TUD_VENDOR

// Vendor FIFO size of TX and RX
// If not configured vendor endpoints will not be buffered
#define CFG_TUD_VENDOR_RX_BUFSIZE (64)
#define CFG_TUD_VENDOR_TX_BUFSIZE (64)

#endif

#if CFG_TUD_CDC

// CDC FIFO size of TX and RX
#define CFG_TUD_CDC_RX_BUFSIZE   (TUD_OPT_HIGH_SPEED ? 512 : 64)
#define CFG_TUD_CDC_TX_BUFSIZE   (TUD_OPT_HIGH_SPEED ? 512 : 64)

// CDC Endpoint transfer buffer size, more is faster
#define CFG_TUD_CDC_EP_BUFSIZE   (TUD_OPT_HIGH_SPEED ? 512 : 64)

#endif

#ifdef __cplusplus
}
#endif

#endif /* _TUSB_CONFIG_H_ */

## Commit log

2023-10-05 first commiting
    [SPDIF.kicad_sch, adc.kicad_sch, amplifer_power_generator.kicad_sch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]
2023-10-13 fixed the english readme contents powerd by ChatGPT
2023-10-26 fix PID in control_uwp
